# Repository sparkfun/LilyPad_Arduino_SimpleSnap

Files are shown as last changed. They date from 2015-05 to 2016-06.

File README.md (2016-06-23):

LilyPad Arduino SimpleSnap
========================================

LilyPad Arduino SimpleSnap

[*LilyPad Arduino SimpleSnap (DEV-10941)*](https://www.sparkfun.com/products/10941)

 The SimpleSnap board is similar to the LilyPad Simple board, and has the same functionality except for two major differences: A built-in rechargeable Lithium Polymer battery and female snap connectors. 
 By adding fabric snaps to the board, LilyPad’s made it possible to connect this board to the SimpleSnap Protoboard or simply an arrangement of sew-on fabric snaps so that the board is removable from your project for washing or so that multiple projects can share a board! 

 Repository Contents
-------------------

* **/Hardware** - Eagle design files (.brd, .sch)
* **/Production** - Production panel files (.brd)

Documentation
--------------
* **[SparkFun Fritzing repo](https://github.com/sparkfun/Fritzing_Parts)** - Fritzing diagrams for SparkFun products.
* **[SparkFun 3D Model repo](https://github.com/sparkfun/3D_Models)** - 3D models of SparkFun products. 

License Information
-------------------
This product is _**open source**_! 

The **hardware** is released under [Creative Commons ShareAlike 4.0 International](https://creativecommons.org/licenses/by-sa/4.0/).

Please use, reuse, and modify these files as you see fit. Please maintain attribution to SparkFun Electronics and release anything derivative under the same license.

Distributed as-is; no warranty is given.

- Your friends at SparkFun.

_**Note:** A portion of this sale is given back to Dr. Leah Buechley for continued development and education of e-textiles and also to Arduino LLC to help fund continued development of new tools and new IDE features._

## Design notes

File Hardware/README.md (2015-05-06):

SparkFun <PRODUCT NAME> Design Files
=====================================

The .sch and .brd files hare are Eagle CAD schematic and PCB design files from SparkFun Electronics.
A freeware version of Eagle can be found [here](http://www.cadsoftusa.com/download-eagle/freeware/). 

License
---------
This product is open source! 
The hardware is released under [Creative Commons ShareAlike 4.0 International](https://creativecommons.org/licenses/by-sa/4.0/).

Please use, reuse, and modify these files as you see fit. Please maintain attribution to SparkFun Electronics and release anything derivative under the same license.

Distributed as-is; no warranty is given.

- Your friends at SparkFun.

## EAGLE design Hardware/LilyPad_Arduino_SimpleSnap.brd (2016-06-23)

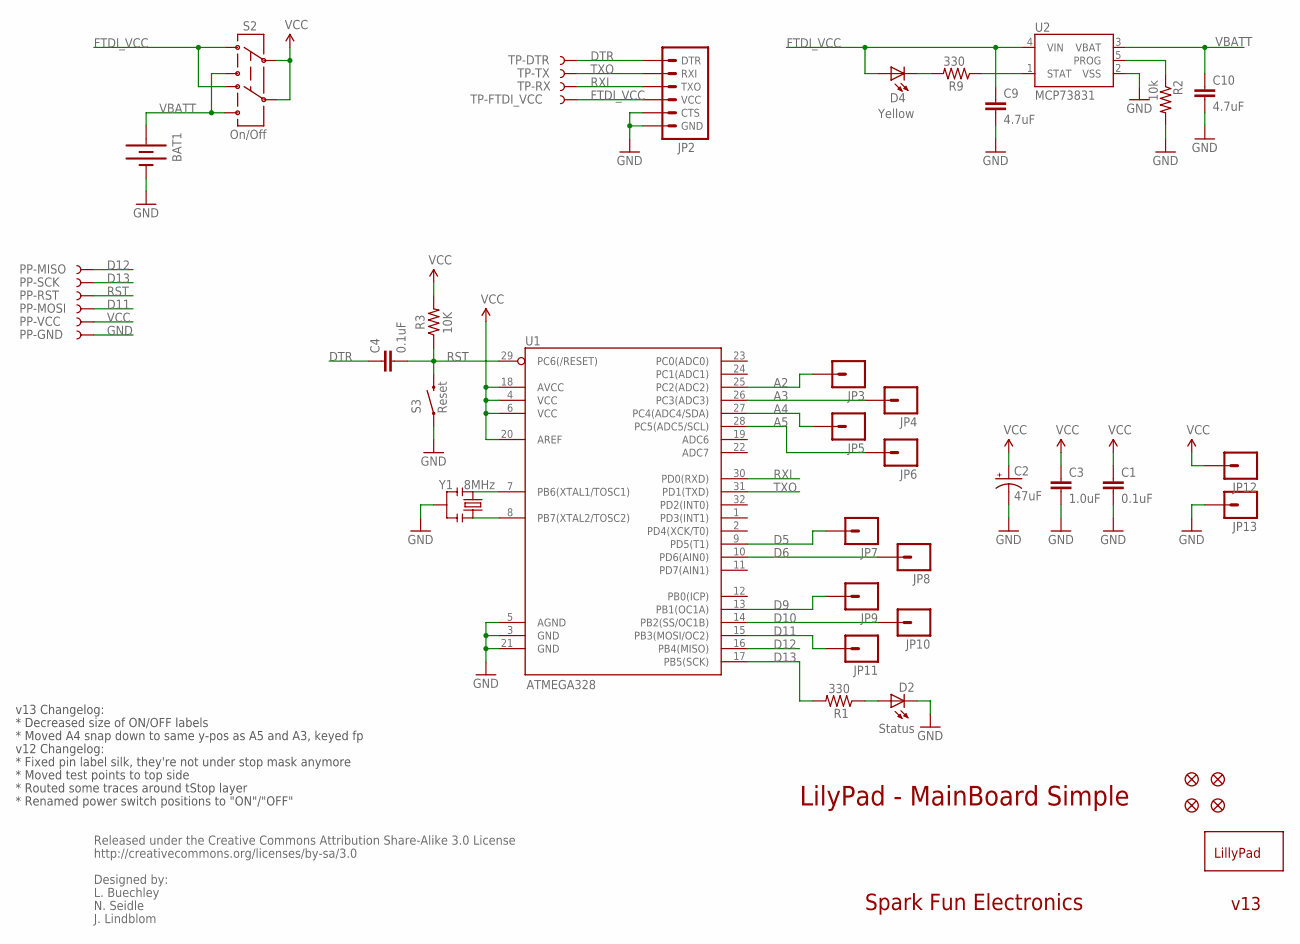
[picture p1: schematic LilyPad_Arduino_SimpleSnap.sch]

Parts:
BAT1: BATTERY110-TABS; LIPO-110-TABS
C1, C4: 0.1uF; 0402-CAP
C2: 47uF; EIA3528
C3: 1.0uF; 0402-CAP
C9, C10: 4.7uF; 0402-CAP
D2: Status; LED-0603
D4: Yellow; LED-0603
JP1, JP14, JP15, JP16: FIDUCIALUFIDUCIAL; MICRO-FIDUCIAL
JP2: ARDUINO_SERIAL_PROGRAMSMD; 1X06-SMD
JP3, JP4, JP5, JP6, JP7, JP8, JP9, JP10, JP11, JP12, JP13: M01SNAP-FEMALE_LARGE; SNAP-FEMALE
PP-GND: TEST-POINT3X5; PAD.03X.05
PP-MISO: TEST-POINT3X5; PAD.03X.05
PP-MOSI: TEST-POINT3X5; PAD.03X.05
PP-RST: TEST-POINT3X5; PAD.03X.05
PP-SCK: TEST-POINT3X5; PAD.03X.05
PP-VCC: TEST-POINT3X5; PAD.03X.05
R1, R9: 330; 0402-RES
R2: 10k; 0402-RES
R3: 10K; 0402-RES
S2: On/Off; AYZ0202
S3: Reset; TACTILE_SWITCH_SMD
TP-DTR: TEST-POINT3X5; PAD.03X.05
TP-FTDI_VCC: TEST-POINT3X5; PAD.03X.05
TP-RX: TEST-POINT3X5; PAD.03X.05
TP-TX: TEST-POINT3X5; PAD.03X.05
U1: ATMEGA328; TQFP32-08
U2: MCP73831; SOT23-5
U$2: LOGO-LPLP; LOGO-LILYPAD
Y1: 8MHz; RESONATOR-SMD

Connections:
A2: JP3.1, U1.25 (PC2(ADC2))
A3: JP4.1, U1.26 (PC3(ADC3))
A4: JP5.1, U1.27 (PC4(ADC4/SDA))
A5: JP6.1, U1.28 (PC5(ADC5/SCL))
D5: JP7.1, U1.9 (PD5(T1))
D6: JP8.1, U1.10 (PD6(AIN0))
D9: JP9.1, U1.13 (PB1(OC1A))
D10: JP10.1, U1.14 (PB2(SS/OC1B))
D11: JP11.1, PP-MOSI.P$1, U1.15 (PB3(MOSI/OC2))
D12: PP-MISO.P$1, U1.16 (PB4(MISO))
D13: PP-SCK.P$1, R1.2, U1.17 (PB5(SCK))
DTR: C4.1, JP2.1 (DTR), TP-DTR.P$1
FTDI_VCC: C9.1, D4.A, JP2.4 (VCC), S2.3 (1), S2.6 (4), TP-FTDI_VCC.P$1, U2.4 (VIN)
GND: BAT1.-, C1.2, C2.C (-), C3.2, C9.2, C10.2, D2.C, JP2.5 (CTS), JP2.6 (GND), JP13.1, PP-GND.P$1, R2.2, S3.1, U1.3 (GND), U1.5 (AGND), U1.21 (GND), U2.2 (VSS), Y1.2
unnamed: U1.7 (PB6(XTAL1/TOSC1)), Y1.1
unnamed: D2.A, R1.1
unnamed: U1.8 (PB7(XTAL2/TOSC2)), Y1.3
unnamed: D4.C, R9.2
PROG: R2.1, U2.5 (PROG)
RST: C4.2, PP-RST.P$1, R3.1, S3.3 (2), U1.29 (PC6(/RESET))
RXI: JP2.3 (TXO), TP-RX.P$1, U1.30 (PD0(RXD))
STAT: R9.1, U2.1 (STAT)
TXO: JP2.2 (RXI), TP-TX.P$1, U1.31 (PD1(TXD))
VBATT: BAT1.+, C10.1, S2.1 (3), S2.4 (6), U2.3 (VBAT)
VCC: C1.1, C2.A (+), C3.1, JP12.1, PP-VCC.P$1, R3.2, S2.2, S2.5, U1.4 (VCC), U1.6 (VCC), U1.18 (AVCC), U1.20 (AREF)

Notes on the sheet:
LilyPad - MainBoard Simple
Spark Fun Electronics
Released under the Creative Commons Attribution Share-Alike 3.0 License
http://creativecommons.org/licenses/by-sa/3.0
Designed by:
L. Buechley
N. Seidle
J. Lindblom
v12 Changelog:
* Fixed pin label silk, they're not under stop mask anymore
* Moved test points to top side
* Routed some traces around tStop layer
* Renamed power switch positions to "ON"/"OFF"
v13 Changelog:
* Decreased size of ON/OFF labels
* Moved A4 snap down to same y-pos as A5 and A3, keyed fp
v13

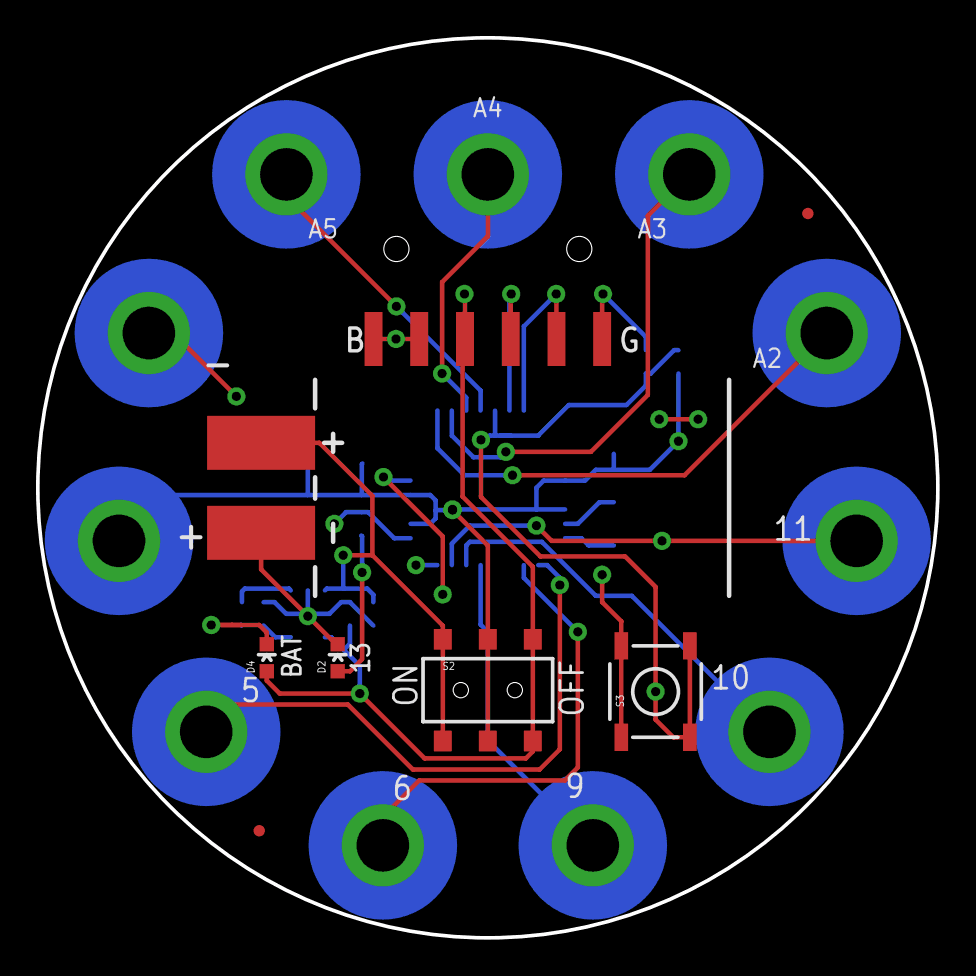
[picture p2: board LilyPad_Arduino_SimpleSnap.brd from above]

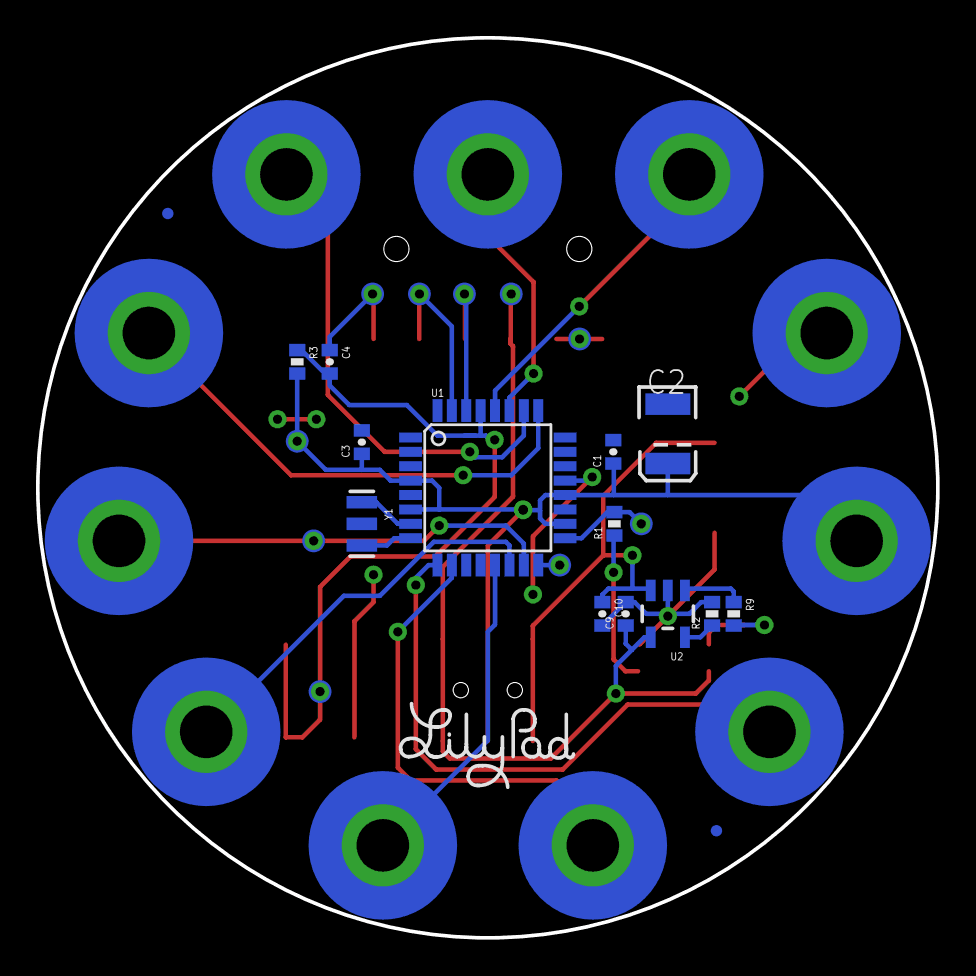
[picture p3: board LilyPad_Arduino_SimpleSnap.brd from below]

Board: 2 copper layers, 50.0 x 50.0 mm, 45 parts (37 on the bottom side), 25 nets.

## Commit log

2015-05-06 Adding hardware files, readme
    [LilyPad_Arduino_SimpleSnap.brd, LilyPad_Arduino_SimpleSnap.sch]
2016-06-23 Fixing resistor value to match actual BOM
    [LilyPad_Arduino_SimpleSnap.brd, LilyPad_Arduino_SimpleSnap.sch]
